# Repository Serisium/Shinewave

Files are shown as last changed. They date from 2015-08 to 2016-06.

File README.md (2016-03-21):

# Overview
Shinewave is a mod for the Nintendo GameCube controller that adds USB joystick functionality, along with LED lighting.

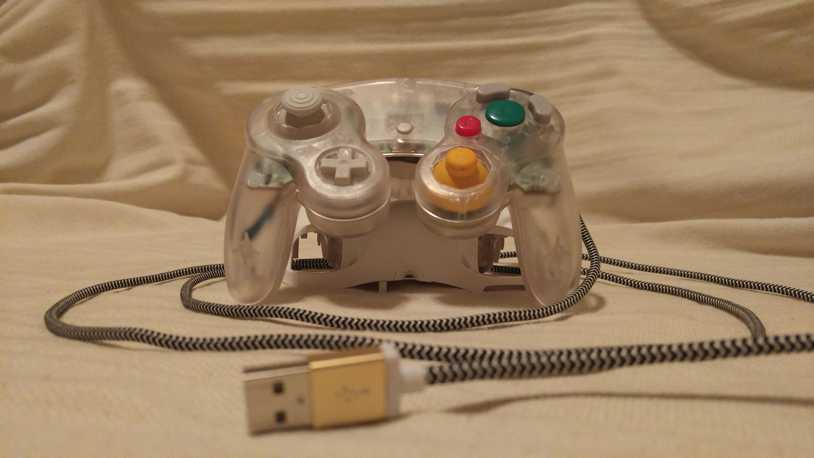
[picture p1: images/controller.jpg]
Controller


# Installation & Usage
Shinewave has been written on a Linux system and requires the full avr-gcc toolchain to make.

In Debian, the toolchain can be set up with the following command.

	sudo apt-get install gcc-avr avr-libc avrdude

In Arch, the toolchain can be set up with the following command.

	sudo pacman -S avr-gcc avr-libc avrdude

Then, download the repository to your local machine

	git clone git@github.com:GGreenwood/Shinewave.git
    cd Shinewave
    git checkout v0.2-usb

There are two ways to install my program onto your ATtiny84: through the micronucleus bootloader, or directly through ISP. I recommend setting up the bootloader since it'll let you reprogram the board without needed to disassemble the controller.

Since the GameCube controller's signal line is connected to one of the ISP programming pins, you must disconnect the controller before programming. This is handled by removing the onboard jumper.

## Bootloader programming
Once you have the project downloaded, you'll need to do the following steps

* Assemble the board and connect your ISP programmer
* Update the `$(PROGRAMMER)` variable in `/bootloader/firmware/Makefile` to reflect your USB programmer
* Flash the micronucleus fuses
* Compile and burn the micronucleus bootloader
* Install the micronucleus command-line client
* Compile the Shinewave project and run the micronucleus uploader
* Connect your circuit to USB

The commands to do the above are as follows:

    # ./Shinewave
    cd bootloader/firmware/
    # update the PROGRAMMER setting
    vim Makefile
    # set the fuses and burn the bootloader
    make fuse
    make flash
    # set up the command-line programmer
    cd ../commandline/
    make
    sudo make install
    sudo cp 49-micronucleus.rules /etc/udev/rules.d/
    # Compile and flash Shinewave
    cd ../firmware/
    make microflash

## Direct programming
This approach is for flashing Shinewave to the board directly, as opposed to through a bootloader. Just like setting up the bootloader, you need an ISP programmer connected to the circuit. However, you'll need to use the ISP programmer every time you want to change the code, not just the first time

    # ./Shinewave
    cd firmware/
    make fuse
    make flash

## Dependencies
This project depends on several libraries, which are listed below.

* Josh Levine's simple [NeoPixel Demo](https://github.com/bigjosh/SimpleNeoPixelDemo) library
* [V-USB](https://www.obdev.at/products/vusb/index.html), for USB communications
* The [micronucleus](https://github.com/micronucleus/micronucleus) USB bootloader

Special thanks also go to [JustANull](https://github.com/JustANull) for C help and [Code and Life](http://codeandlife.com/) for having so many amazing V-USB tutorials.

# Schematics and Board
The schematics and layout for this project were done in EAGLE. The source files are located in the `/circuit` folder, and exported images of the output are available below, or in `/images`.

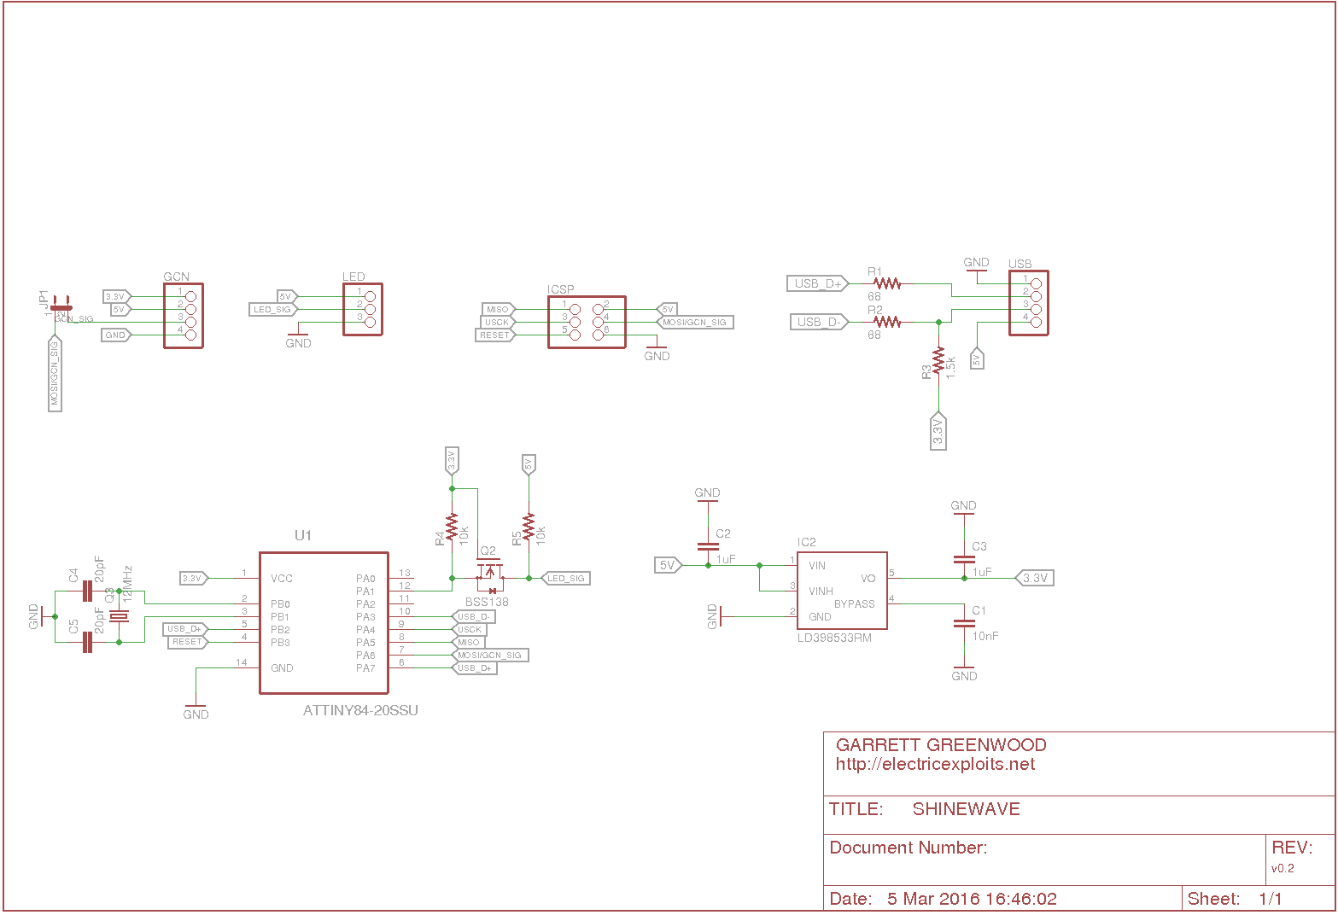
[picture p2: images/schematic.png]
Schematics

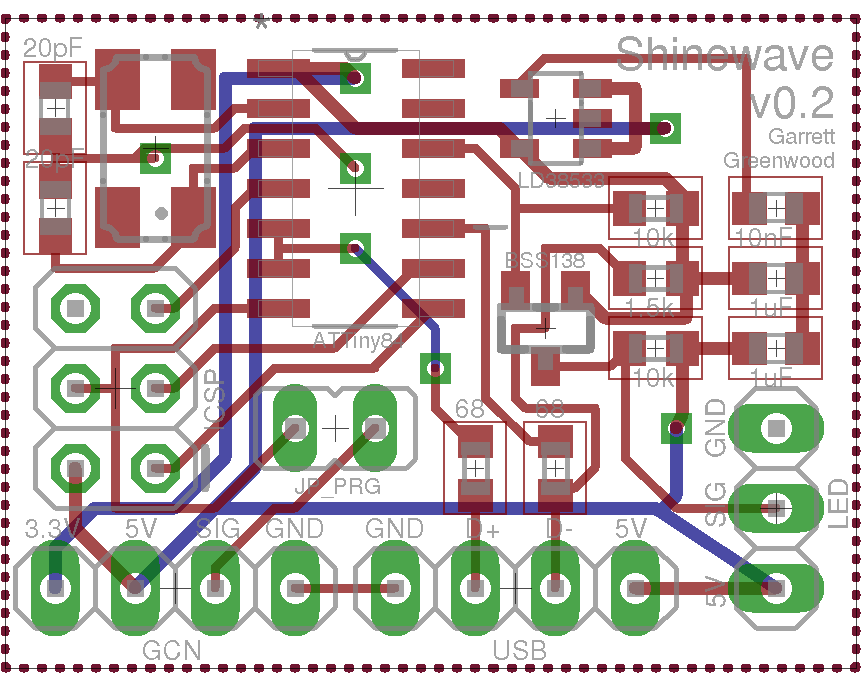
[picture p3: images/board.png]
Board


# Changelog

## [v0.2](https://github.com/GGreenwood/Shinewave/releases/tag/v0.2)
[Original post](http://electricexploits.net/gamecube-controller-usb-conversion-mod/)

* Added schematics and layout
* Added USB joystick functionality
* Added micronucleus bootloader
* Removed protothread dependency
* Changed from the ATtiny85 to the ATtiny84
* Reduced running voltage from 5V to 3.3V and clock speed from 16MHz to 12MHz

## [v0.1.1](https://github.com/GGreenwood/Shinewave/tree/v0.1.1)

* Added a variable delay to fix compatibility with nonstandard messaging speeds. 
* Fixed up Makefile and documentation.

## [v0.1](https://github.com/GGreenwood/Shinewave/releases/tag/v0.1-falco)
[Video](https://www.youtube.com/watch?v=1U4EOI_aFdc)

[Original post](http://electricexploits.net/shinewave/)

[Programming guide](http://electricexploits.net/programming-the-waveshine-prototype-part1/)

[Signal reading overview](http://electricexploits.net/programming-the-waveshine-prototype-part2/)

[Featured on Hackaday](http://hackaday.com/2015/08/02/shinewave-gamecube-controller-is-shiny/) 

[Featured on Kotaku](http://kotaku.com/gamecube-controller-responds-to-smash-bros-moves-with-1721711510)

* Initial release
* Reactive LED mod
* Hard-coded Falco animations, using the protothread library

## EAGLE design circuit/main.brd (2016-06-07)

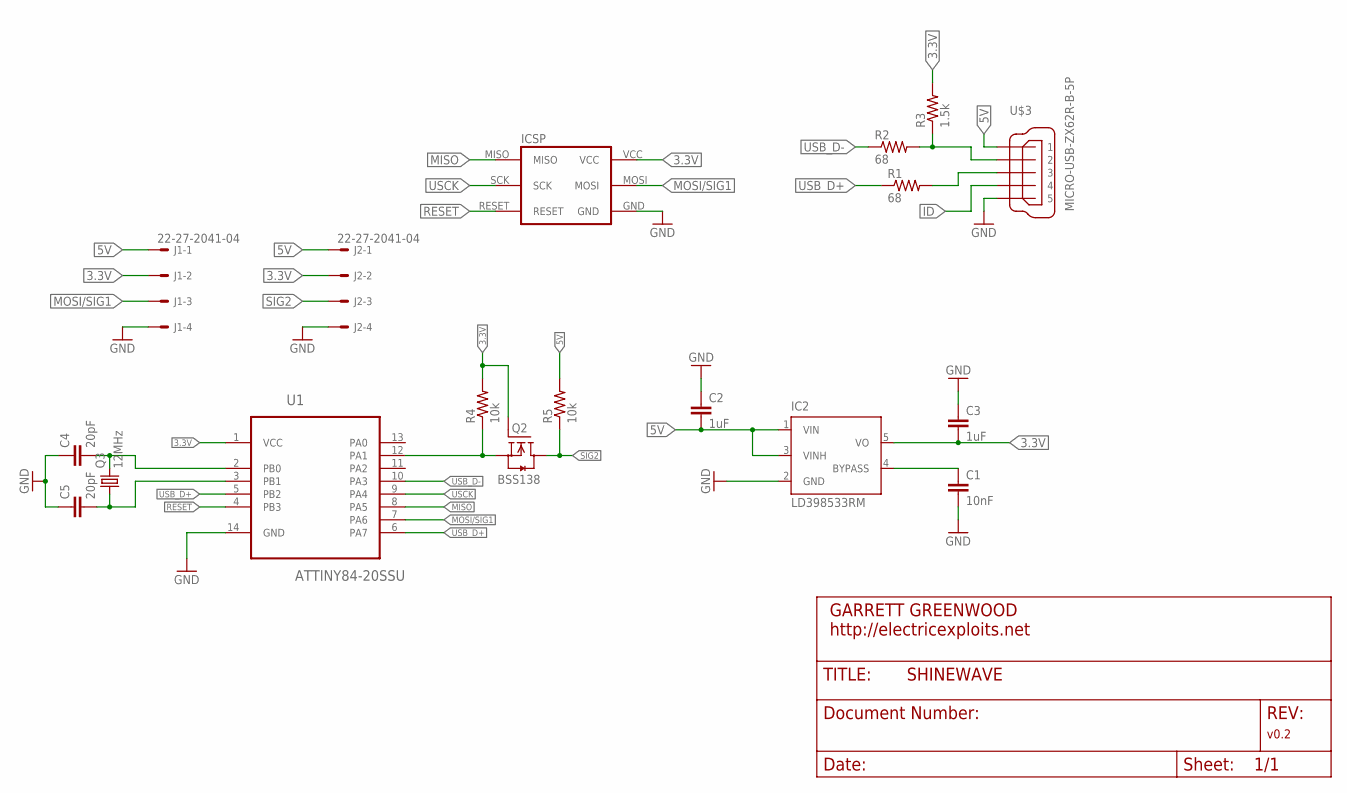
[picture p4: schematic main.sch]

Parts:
C1: 10nF; C0603
C2, C3: 1uF; C0603
C4, C5: 20pF; C0603
IC2: LD398533RM; SOT23-5L
J1, J2: 22-27-2041-04; 6410-04
Q2: BSS138; SOT23
Q3: 12MHz; CTS406
R1, R2: 68; R0603
R3: 1.5k; R0603
R4, R5: 10k; R0603
U1: ATTINY84-20SSU; SOIC127P600X175-14N
U$1: ICSP_POGO_INTERFACE; ICSP_SMD
U$3: MICRO-USB-ZX62R-B-5P; ZX62R-B-5P

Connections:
3.3V: C3.2, IC2.5 (VO), J1.2, J2.2, Q2.1 (G), R3.2, R4.2, U1.1 (VCC), U$1.VCC
5V: C2.2, IC2.1 (VIN), IC2.3 (VINH), J1.1, J2.1, R5.2, U$3.1
GND: C1.2, C2.1, C3.1, C4.1, C5.1, IC2.2 (GND), J1.4, J2.4, U1.14 (GND), U$1.GND, U$3.5
ID: U$3.4
MISO: U1.8 (PA5), U$1.MISO
MOSI/SIG1: J1.3, U1.7 (PA6), U$1.MOSI
unnamed: Q2.2 (S), R4.1, U1.12 (PA1)
unnamed: R2.2, R3.1, U$3.2
unnamed: C1.1, IC2.4 (BYPASS)
unnamed: R1.2, U$3.3
RESET: U1.4 (PB3), U$1.RESET
SIG2: J2.3, Q2.3 (D), R5.1
USB_D+: R1.1, U1.5 (PB2), U1.6 (PA7)
USB_D-: R2.1, U1.10 (PA3)
USCK: U1.9 (PA4), U$1.SCK
XTAL1: C4.2, Q3.3 (2), U1.2 (PB0)
XTAL2: C5.2, Q3.1, U1.3 (PB1)

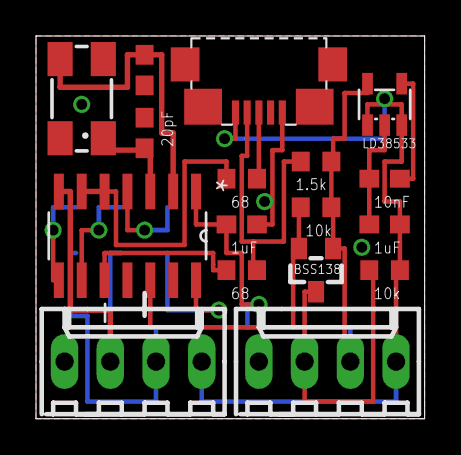
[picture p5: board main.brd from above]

Board: 2 copper layers, 21.6 x 21.3 mm, 18 parts (0 on the bottom side), 16 nets.

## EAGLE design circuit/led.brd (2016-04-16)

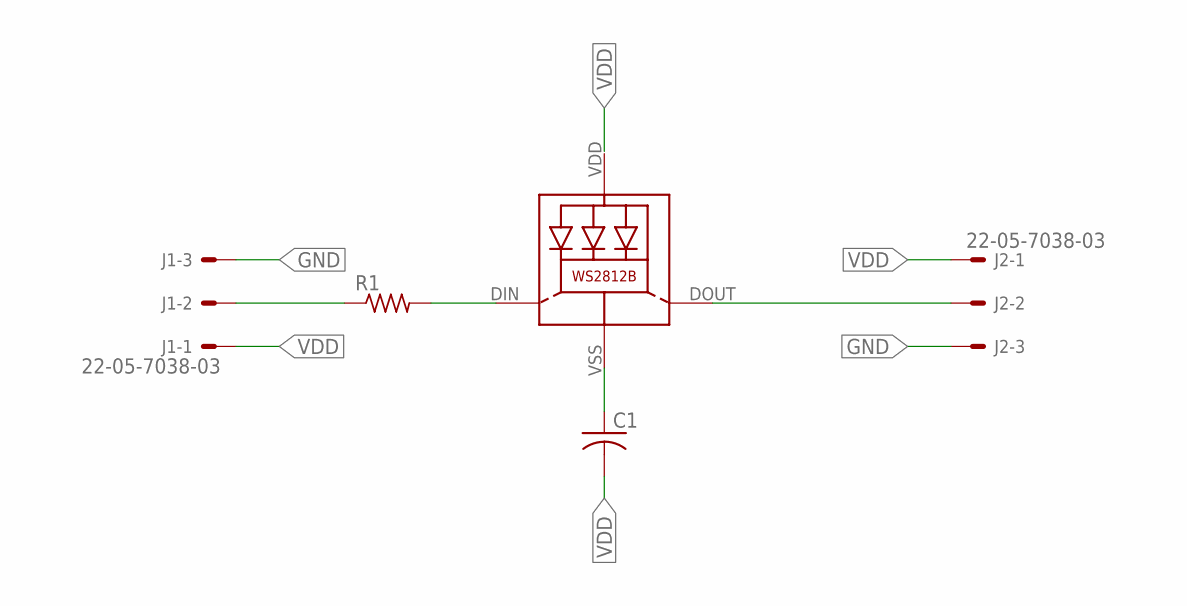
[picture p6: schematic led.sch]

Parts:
C1: C-USC0603; C0603
J1, J2: 22-05-7038-03; 7395-03
LED1: WS2812B
R1: R-US_R0603; R0603

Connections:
GND: C1.1, J1.3, J2.3, LED1.VSS (GND)
unnamed: J1.2, R1.1
unnamed: LED1.DIN (DI), R1.2
unnamed: J2.2, LED1.DOUT (DO)
VDD: C1.2, J1.1, J2.1, LED1.VDD

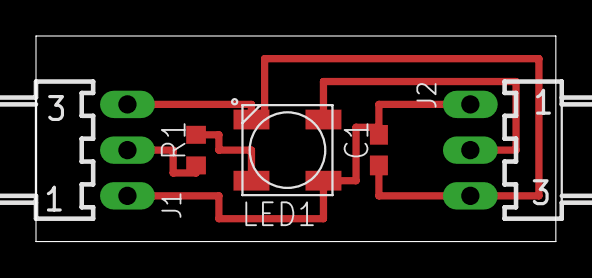
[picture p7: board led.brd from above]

Board: 2 copper layers, 28.9 x 11.4 mm, 5 parts (0 on the bottom side), 5 nets.

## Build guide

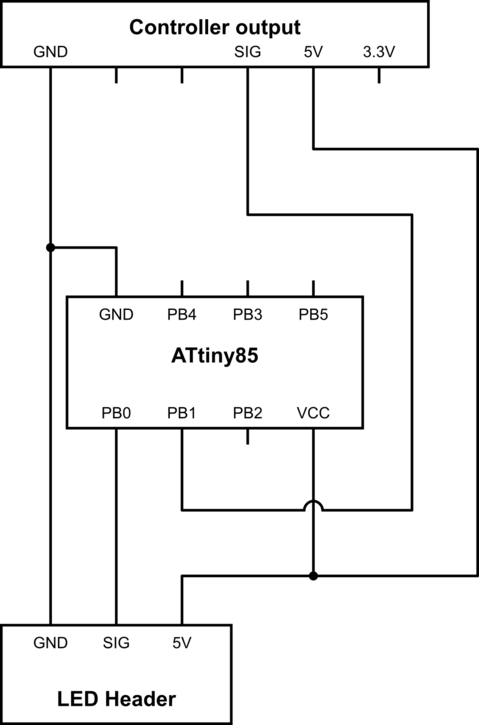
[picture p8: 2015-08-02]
images/wiring.png

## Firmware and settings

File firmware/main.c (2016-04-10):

#include <avr/interrupt.h>
#include <avr/wdt.h>
#include <stdint.h>
#include <util/delay.h>

#include "controller.h"
#include "libs/Neopixel.h"
#include "usb.h"
#include "usbdrv/usbdrv.h"

#define DEBUG_MATCH 0   // Enable PIN_TIMER toggle on timer match
#define GCN_RETRY_LIMIT 5   // Number of times to retry the GCN signal line

#define PIN_DEBUG PA2
#define PIN_GC    PA6   // Needs to be connected to (DI)
//#define PIN_TIMER PA7   // Needs to be connected to (OC0B). Displays compare match toggles if DEBUG_MATCH is set

#define GET_BIT(TGT, PIN)    ((TGT) & (1 << (PIN)))
#define SET_BIT(TGT, PIN)    do { TGT |=  (1 << (PIN)); } while(0)
#define CLEAR_BIT(TGT, PIN)  do { TGT &= ~(1 << (PIN)); } while(0)
#define TOGGLE_BIT(TGT, PIN) do { TGT ^=  (1 << (PIN)); } while(0)

#define SEND_ZERO()        do { CLEAR_BIT(PORTA, PIN_GC); _delay_us(3); SET_BIT(PORTA, PIN_GC); _delay_us(1); } while(0)
#define SEND_ONE()         do { CLEAR_BIT(PORTA, PIN_GC); _delay_us(1); SET_BIT(PORTA, PIN_GC); _delay_us(3); } while(0)

void setup_pins(void) {
    CLEAR_BIT(DDRA, PIN_GC);		// Set PIN_GC as input, GCN data signal
    SET_BIT(PORTA, PIN_GC);		    // Enable pull-up resistor on PIN_GC
    SET_BIT(DDRA, PIN_DEBUG);       // Set PIN_DEBUG as output for debugging

    // Ensure that USB pins are inputs with pullup resistor disabled
    CLEAR_BIT(DDRB, PB2);
    CLEAR_BIT(DDRA, PA3);
    CLEAR_BIT(DDRA, PA7);
    CLEAR_BIT(PORTB, PB2);
    CLEAR_BIT(PORTA, PA3);
    CLEAR_BIT(PORTA, PA7);

    #if DEBUG_MATCH == 1
    SET_BIT(DDRA, PIN_TIMER);       // Set PIN_TIMER as output for compare matches
    #endif
    ledsetup();
}

void enable_timer0(void) {
    TCNT0 = 0;
    TIFR0 = 0xff;                   // Reset interrupt flags

    #if DEBUG_MATCH == 1
    // Set 0C0B(PA7) to toggle on match(COM0B=01)
    SET_BIT(TCCR0A, COM0B0);
    #endif

    // Enable Timer/Counter0 module at no prescaler
    SET_BIT(TCCR0B, CS00);
}

void disable_timer0(void) {
    #if DEBUG_MATCH == 1
    // Set 0C0B(PA7) to toggle on match(COM0B=01)
    CLEAR_BIT(TCCR0A, COM0B0);
    #endif

    // Disable Timer/Counter0 module
    CLEAR_BIT(TCCR0B, CS00);
}

// Set Timer/Counter0 in normal mode(WGM=000)
void setup_timer0(void) {
    disable_timer0();

    // Set compare match to signal critical point(2us)
    OCR0A = 2e-6 * F_CPU;   // Triggers USI clock source

    #if DEBUG_MATCH == 1
    OCR0B = 2e-6 * F_CPU;   // Triggers debug toggle
    #endif
}

void enable_usi(void) {
    // Enable Universal Serial Module in Two-wire mode(USIWM=10)
    SET_BIT(USICR, USIWM1);
}

void disable_usi(void) {
    // Disable Universal Serial Module
    SET_BIT(USICR, USIWM1);
}

void setup_usi(void) {
    // Set clock source to Timer/Counter0 Compare Match(USICS=01)
    SET_BIT(USICR, USICS0);
}

void setup_usb(void) {
    cli();
    wdt_enable(WDTO_1S);    // enable 1s watchdog timer
    usbInit();

    usbDeviceDisconnect();  // enforce re-enumeration
    uint8_t i;
    for(i = 0; i<250; i++) {
        wdt_reset();
        _delay_ms(2);
    }
    usbDeviceConnect();
    sei();
}

void init_controller(void) {
    SET_BIT(PORTA, PIN_GC);         // Set positive output on PIN_GC
    SET_BIT(DDRA, PIN_GC);          // Set PIN_GC as output

    // Send controller init message (000000001)
    for(uint8_t bit = 0; bit < 8; bit++) {
        SEND_ZERO();
    }
    SEND_ONE();

    CLEAR_BIT(DDRA, PIN_GC);        // Set PIN_GC as input
}

uint8_t request_message(uint8_t *message_buffer) {
    uint8_t cur_byte = 0;

    USISR = 0b11101000;             // Reset USI Interrupt flags and set timer value to 8
    disable_usi();
    disable_timer0();

    asm("nop; nop; nop;");

    SET_BIT(DDRA, PIN_GC);          // Set PIN_GC as output
    CLEAR_BIT(PORTA, PIN_GC);

    // Send controller data request
    SEND_ZERO(); SEND_ONE();  SEND_ZERO(); SEND_ZERO(); SEND_ZERO(); SEND_ZERO(); SEND_ZERO(); SEND_ZERO();
    SEND_ZERO(); SEND_ZERO(); SEND_ZERO(); SEND_ZERO(); SEND_ZERO(); SEND_ZERO(); SEND_ONE();  SEND_ONE();
    SEND_ZERO(); SEND_ZERO(); SEND_ZERO(); SEND_ZERO(); SEND_ZERO(); SEND_ZERO(); SEND_ONE();  SEND_ZERO();
    SEND_ZERO();

    SET_BIT(PORTA, PIN_GC);
    CLEAR_BIT(DDRA, PIN_GC);        // Set PIN_GC as input

    // Start reading the message
    enable_usi();
    enable_timer0();
    while(1) {
        // Wait for signal to go low
        while(GET_BIT(PINA, PIN_GC)) {
            // Catch a timer overflow as an exit condition
            // This occurs if the signal is high for > 255 cycles
            if(GET_BIT(TIFR0, TOV0)) {
                // Exit condition
                disable_usi();

                // Wait for the timer to overflow and loop once, fixes 'every other' corruption
                while(TCNT0 < 24) {}

                // Check if there's no signal on the line
                if(cur_byte == 0) {
                    SET_BIT(PORTA, PIN_DEBUG);
                    CLEAR_BIT(PORTA, PIN_DEBUG);
                    return 0;
                }

                disable_timer0();
                return 1;
            }
        }
        // Reset Timer0, a little higher than 0 to account for polling delay
        TCNT0 = 5;

        if(GET_BIT(USISR, USIOIF)) {
            // Skip the counter to 8 of 16
            SET_BIT(USISR, USICNT3);

            // Store the byte from the serial buffer
            message_buffer[cur_byte] = USIBR;
            cur_byte++;

            // Toggle the debug pin
            SET_BIT(PORTA, PIN_DEBUG);
            CLEAR_BIT(PORTA, PIN_DEBUG);

            // Clear the overflow counter
            SET_BIT(USISR, USIOIF);
        }

        // Make sure signal is high before looping
        // Hardware should pull up DIN or risk an infinite loop
        while(!GET_BIT(PINA, PIN_GC)) {}
    }

    // Unreachable code
    return 0;
}

int main(void)
{
    setup_pins();
    setup_timer0();
    setup_usi();
    setup_usb();
    init_controller();

    uint8_t retry_count = 0;

    uint8_t message_buffer[8] = {0};
    Controller *controller = (Controller*)message_buffer;

    while(1) {
        showColor(255, 0, 0, 8);
        usbPoll();
        wdt_reset();

        if(usbInterruptIsReady()) {
            // Zero out input array
            for(uint8_t i = 0; i < 8; ++i) {
                message_buffer[i] = 0xf0;
            }
            // Try to grab the controller state
            retry_count = GCN_RETRY_LIMIT;
            while(retry_count--) {
                if(request_message(message_buffer)) {
                    build_report(controller, &reportBuffer);
                    usbSetInterrupt((void *)&reportBuffer, sizeof(reportBuffer));
                    if(reportBuffer.rx == 255) {
                        _delay_us(1);
                    }
                    break;
                }

                if(retry_count == 1) {
                    showColor(0, 255, 0, 8);
                }
            }
        }
    }
}

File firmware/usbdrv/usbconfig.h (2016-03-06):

/* Name: usbconfig.h
 * Project: V-USB, virtual USB port for Atmel's(r) AVR(r) microcontrollers
 * Author: Christian Starkjohann
 * Creation Date: 2005-04-01
 * Tabsize: 4
 * Copyright: (c) 2005 by OBJECTIVE DEVELOPMENT Software GmbH
 * License: GNU GPL v2 (see License.txt), GNU GPL v3 or proprietary (CommercialLicense.txt)
 * This Revision: $Id$
 */

#ifndef __usbconfig_h_included__
#define __usbconfig_h_included__

/*
General Description:
This file is an example configuration (with inline documentation) for the USB
driver. It configures V-USB for USB D+ connected to Port D bit 2 (which is
also hardware interrupt 0 on many devices) and USB D- to Port D bit 4. You may
wire the lines to any other port, as long as D+ is also wired to INT0 (or any
other hardware interrupt, as long as it is the highest level interrupt, see
section at the end of this file).
*/

/* ---------------------------- Hardware Config ---------------------------- */

#define USB_CFG_IOPORTNAME      A
/* This is the port where the USB bus is connected. When you configure it to
 * "B", the registers PORTB, PINB and DDRB will be used.
 */
#define USB_CFG_DMINUS_BIT      3
/* This is the bit number in USB_CFG_IOPORT where the USB D- line is connected.
 * This may be any bit in the port.
 */
#define USB_CFG_DPLUS_BIT       7
/* This is the bit number in USB_CFG_IOPORT where the USB D+ line is connected.
 * This may be any bit in the port. Please note that D+ must also be connected
 * to interrupt pin INT0! [You can also use other interrupts, see section
 * "Optional MCU Description" below, or you can connect D- to the interrupt, as
 * it is required if you use the USB_COUNT_SOF feature. If you use D- for the
 * interrupt, the USB interrupt will also be triggered at Start-Of-Frame
 * markers every millisecond.]
 */
#define USB_CFG_CLOCK_KHZ       (F_CPU/1000)
/* Clock rate of the AVR in kHz. Legal values are 12000, 12800, 15000, 16000,
 * 16500, 18000 and 20000. The 12.8 MHz and 16.5 MHz versions of the code
 * require no crystal, they tolerate +/- 1% deviation from the nominal
 * frequency. All other rates require a precision of 2000 ppm and thus a
 * crystal!
 * Since F_CPU should be defined to your actual clock rate anyway, you should
 * not need to modify this setting.
 */
#define USB_CFG_CHECK_CRC       0
/* Define this to 1 if you want that the driver checks integrity of incoming
 * data packets (CRC checks). CRC checks cost quite a bit of code size and are
 * currently only available for 18 MHz crystal clock. You must choose
 * USB_CFG_CLOCK_KHZ = 18000 if you enable this option.
 */

/* ----------------------- Optional Hardware Config ------------------------ */

/* #define USB_CFG_PULLUP_IOPORTNAME   D */
/* If you connect the 1.5k pullup resistor from D- to a port pin instead of
 * V+, you can connect and disconnect the device from firmware by calling
 * the macros usbDeviceConnect() and usbDeviceDisconnect() (see usbdrv.h).
 * This constant defines the port on which the pullup resistor is connected.
 */
/* #define USB_CFG_PULLUP_BIT          4 */
/* This constant defines the bit number in USB_CFG_PULLUP_IOPORT (defined
 * above) where the 1.5k pullup resistor is connected. See description
 * above for details.
 */

/* --------------------------- Functional Range ---------------------------- */
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

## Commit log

2015-06-27 Fixed endianness of controller POC definition
    [main.c]
2015-06-29 Added smooth animation lookups and a jump thread
2015-07-17 Added exit condition on max frame
2015-08-30 Updated project name and added make fuse command
2015-08-31 Reduced timer complexity
2015-10-13 Modified code to run at 3.3V/12.8MHz rather than 5V/16MHz
2015-11-07 added controller code and fixed stutter; is silly
    [main.c, usbconfig.h]
2015-12-19 Refactored usb.c and added timer behavior for new SPI implementation
2015-12-22 Added USI code in Two-Wire mode
2015-12-23 Fixed half-broken behavior, am still spooked by the R button
    [main.c]
2016-01-13 'fixed' issue with R button by adding a retry loop
    [main.c]
2016-01-27 Added v0.2 of PCB
2016-02-09 Added EAGLE files for v0.2 PCB
    [main.brd, main.sch]
2016-02-09 Updated pins and fuses for PCB prototype v0.2
2016-02-09 Fixed stack overflow when no controller is connected by adding a retry limit
    [main.c]
2016-02-10 Added LED test code
2016-02-29 Updated fuses for bootloader
2016-03-06 Added schematic and board images
2016-03-06 Updated v0.2 schematics to include title frame
    [main.sch]
2016-03-06 Added proper PID/VID pair
2016-03-26 Initial run of include-what-you-use
    With a couple of edits to fit the surrounding style. Hopefully makes
    files more accurate in immediate identification of what their
    dependencies are, rather than relying on another header transitively
    including them.
2016-03-26 Make recursively clean
    The current rm command only checks the current directory and the listed
    ones, in particular skipping other subdirectories.
    Perhaps switch this out to something that operates with the Makefile
    variables, avoiding the `find` command entirely?
2016-04-10 Updated circuit for Shinewave v0.3
    [main2.brd, main2.sch]
2016-04-10 removed duplicate circuit files
    [main2.brd, main2.sch]
2016-04-10 Made changes to button/analog layout for better support with Rivals of Aether
2016-04-16 Added sample PCB for mountable LEDs
    [led.brd, led.sch]
2016-06-07 Updated circuit for Shinewave v0.3.1
    [main.brd, main.sch]
2016-06-07 Reverted wobbles' code being pushed to the main branch
    [main.c]

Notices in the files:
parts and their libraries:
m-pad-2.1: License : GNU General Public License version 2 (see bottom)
